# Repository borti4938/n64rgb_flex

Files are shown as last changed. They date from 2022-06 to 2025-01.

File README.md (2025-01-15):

N64RGBv3 / N64RGB_Flex (PCB & Fw)
---

This repository contains all you need files to build your own DIY N64RGBv3 / N64RGB_Flex board.
Firmware is supplied in this repository, too.

Please don't ask me for selling a modding.
I either sell some prototypes on some forums marketplaces (which is very unlikely) or I don't have any of the boards.
This is a complete DIY modding project.
Everybody is on his own here.

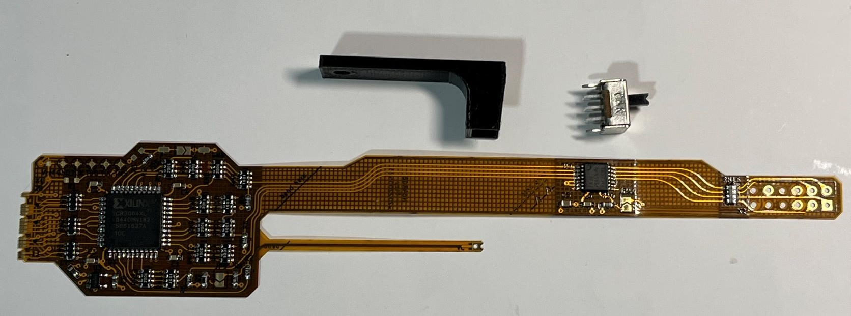
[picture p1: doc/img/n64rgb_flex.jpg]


**Note:** Images showing an older version of the PCB.
PCB was updated to reduce costs and due to CPLDs became end of life.

**WARNING:**
This is an advanced DIY project if you do everything on your own.
You need very good soldering skills.
The CPLD has 0.4mm fine pitched pins, the video amp 0.65mm pitch.
On the board there are some 4x0402 and 4x0603 resistor and ferrite bead arrays, as well as some tiny 0402 caps.
However, there might be some awesome shops out there selling the boards for a great price.

## Table of Contents

- [Checklist](https://github.com/borti4938/n64rgb_flex#checklist-how-to-build-the-project)
- [Assembly](https://github.com/borti4938/n64rgb_flex#assembly)
- [Installation](https://github.com/borti4938/n64rgb_flex#installation)
  - [1. Open the Console](https://github.com/borti4938/n64rgb_flex#1-open-the-console)
  - [2. Solder Work](https://github.com/borti4938/n64rgb_flex#2-solder-work)
  - [3. Jumper Setup](https://github.com/borti4938/n64rgb_flex#3-jumper-setup)
  - [4. Finish the Work](https://github.com/borti4938/n64rgb_flex#4-finish-the-work)
- [Firmware](https://github.com/borti4938/n64rgb_flex#firmware)
- [Cable Setup](https://github.com/borti4938/n64rgb_flex#cable-setup)

## Checklist: How to build the project

- Use PCB files (either [KiCad-PCB design file](./pcb/n64rgb_v3.kicad_pcb) or [Gerber files](./pcb/gerber/)) to order your own PCB with following specs (might be not comprehensive)  
  - Size: 160.28mm x 25.45mm
  - Layer: 2
  - FPC thickness: 0.12mm
  - Min hole size: dia 0.2mm / ring 0.4mm or lower
  - Min trace width / spacing: 0.15mm
  - Stiffener: Polyimide (bottom only)
  - Polyimide thickness: 0.15mm  
  There are two variants: _diy_ and _prod_. The _diy_ variant has larger via under the exposed pad and an opening in the stiffener under it in order to make soldering with standard soldering iron feasible. The _prod_ variant has smaller vias and no opening; so production assembly or use of soldering paste with hot air is mandatory.
- If you paln to use solder paste, do not forget to order a stencil for top
- Source the components you need, e.g. from Mouser or Digikey.  
  The BOM is available in [here](./doc/ibom.html).
- Wait for everything to arrive
- Assemble your PCB if you haven't use a PCBA service
- Flash the [Firmware](https://github.com/borti4938/n64rgb_flex#firmware) either before or after installation into the N64
- Set all jumpers

## Assembly

If you have all components available, you can start assembly your board.
**Please note**: if you plan to flash the firmware before assembly, go to the [Firmware](https://github.com/borti4938/n64rgb_flex#firmware) section first.
The documentation provides an [interactive BOM](./doc/ibom.html), which should guide you through the assbly.
There is no specific order for the assembly - just take your time.

Using non-clean flux (rosin based) is obviously recommended.
Even though it is "non-clean" I recommend cleaning everything afterwards (just for the visual finish).

Please double check everything for shorts once you finished your work.
Very important is that the power supply trace do not short to GND.
- 5V against GND (e.g. at C9 and at MultiOut pin 10 to 6)
- 3.3V against GND (e.g. at C11)
- 1.8V against GND (e.g. at C10)

Flash the firmware after assembly if you plan to do so.

## Installation

### 1. Open the console

- Remove Jumper Pak / Expansion Pak
- Remove screws from bottom side of the console  
(needs a 4.5mm gamebit tool)
- Lift top housing
- remove inner screws as marked  
(very last consoles made the heat sink design changed slightly)
- pull out the mainboard
- remove heat sink and RF shield
- **Hint** Now you have the chance to clean up your N64 shell

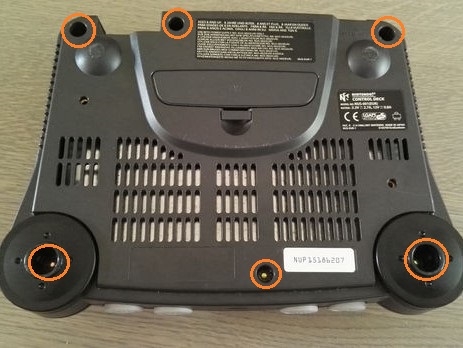
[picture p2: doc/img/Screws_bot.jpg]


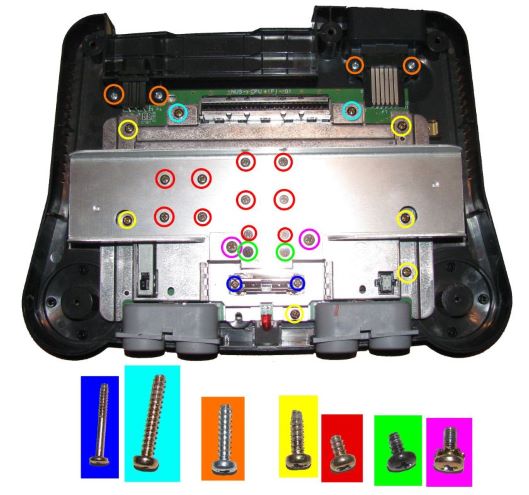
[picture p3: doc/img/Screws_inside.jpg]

(image by Zerberus (circuit-board.de user))

### 2. Solder Work

This PCB is designed as a custom flex cable which fits nicely into every N64.

#### 2.1 Digital inputs

Start with the digital side:
- Bend the input side like in an S-shape.  
This helps the solder connection to have minimal mechanical stress.

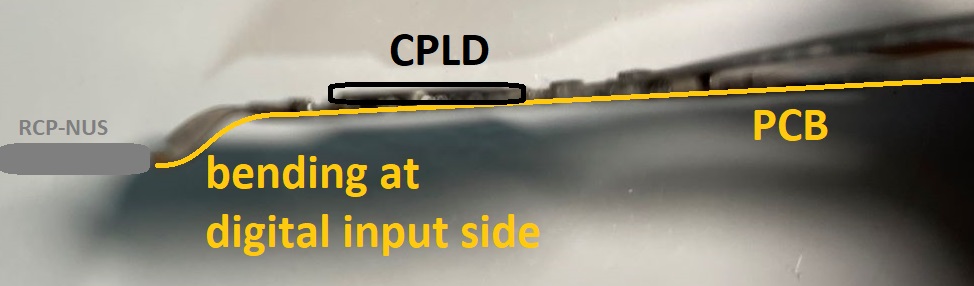
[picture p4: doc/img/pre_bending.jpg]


- Solder the RCP connector side to the RCP-NUS as shown
  - first pin bottom – 11
  - last pin to – 28
- Take your time for this step - after this one you are almost finished with your work

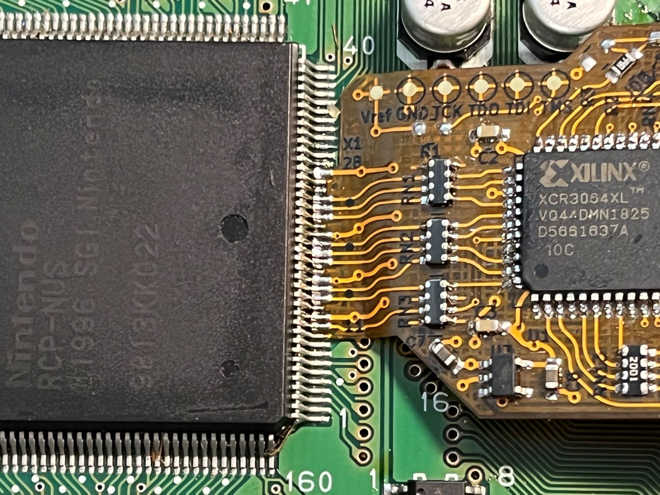
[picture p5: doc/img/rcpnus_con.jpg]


#### 2.2 Analog output

- Route the flex pcb to the MultiOut as shown.  
You need three bends:
  - Two rather sharp 90 degree ones
  - One round bending around the N64 PCB

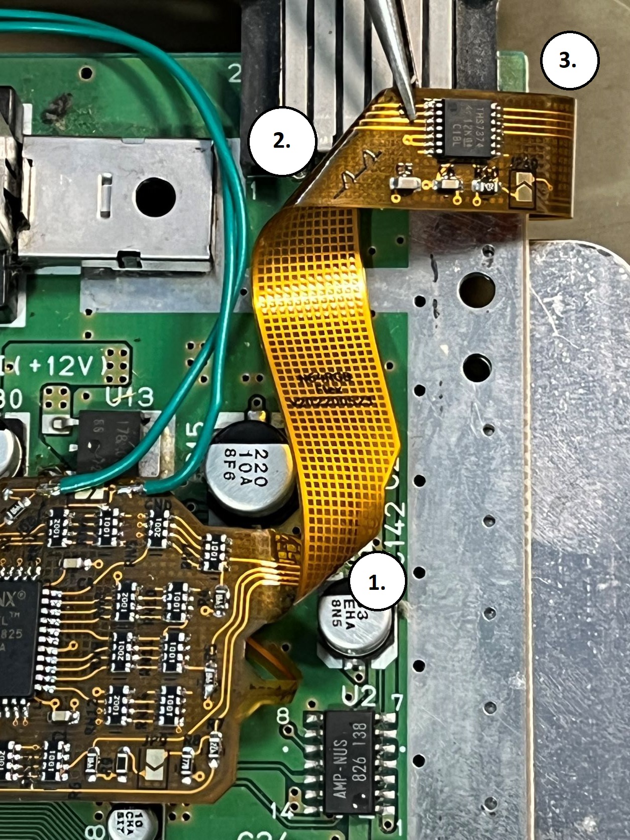
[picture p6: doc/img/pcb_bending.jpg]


- Solder the MultiOut footprint to the MultiOut pins

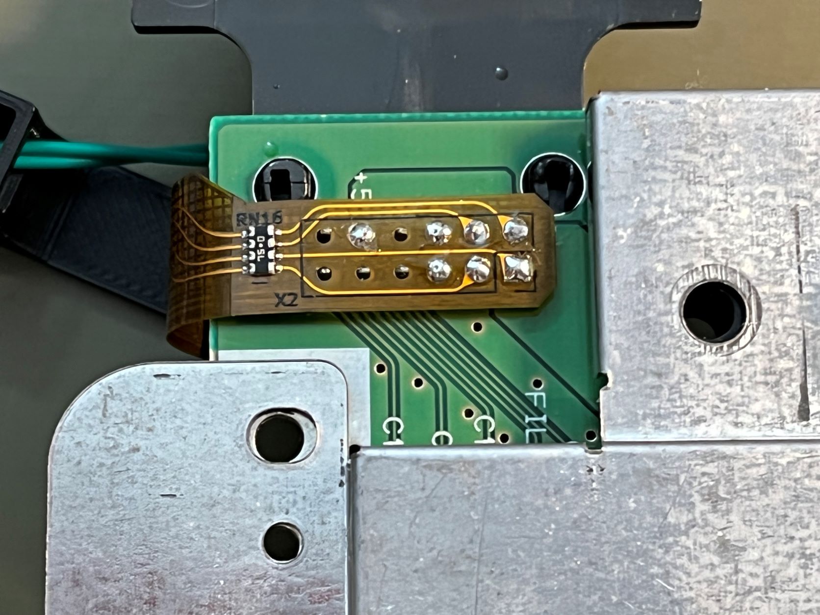
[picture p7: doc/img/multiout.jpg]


#### 2.3 Additional Step for NUS-CPU-01/-02/-03 boards

- remove R14
- or cut the trace going to pin 3 of the MultiOut

### 3. Jumper Setup

#### JP9 (CSYNC level @ pin 3 MultiOut)

- opened: appr. 1.87V @ 75ohm termination, i.e. needs a resistor inside the sync wire further attenuating the signal. Designed to work for cables with 470 ohm resistor inside resulting in appr. 450mV @ 75ohm termination
- closed: appr. 300mV @ 75ohm termination suitable for pass through wired cables at sync, works with standard TV / scaler setup

#### JP10 (low pass filter THS7374)

- opened: use low pass filter
- closed: bypass

#### JP11 - JP13 (Cable)

- all opened: NTSC cable
- all closed: PAL cable

#### JDB

For this jumper, it is recommended to use a slide switch (part no. is provided in the [BOM](./doc/ibom.html))

- opened: do not use vi-deblur for 240p output
- closed: permanently use vi-deblur for 240p output (not recommended at all)

### 4. Finish the Work

#### 4.1 VI-Deblur Switch

If you source the switch as provided in the [BOM](./doc/ibom.html), you can use [this 3D mount](https://www.thingiverse.com/thing:4584239) for a clean installation.
A copy of the STL is also provided [here](./3d_print/).
Please note and respect the license of the switch!

- Prepare the switch by cutting off two pins and a housing pin
- solder two wire of appr. 10cm length to a middle and an outside pin of the switch (same side)

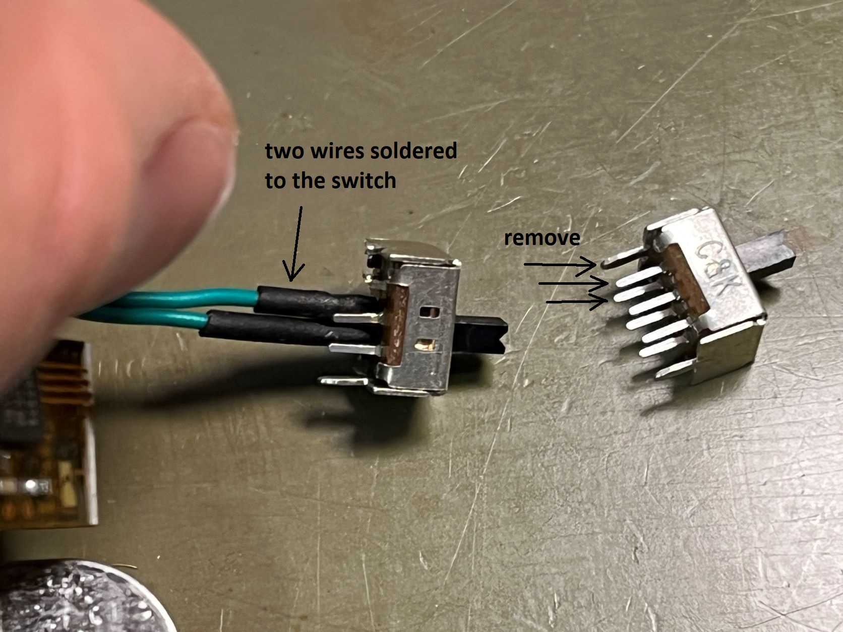
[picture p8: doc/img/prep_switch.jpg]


- run the wires through the 3d printed mount to the flex pcb
- solder the wires to the pads next to the JDB jumper

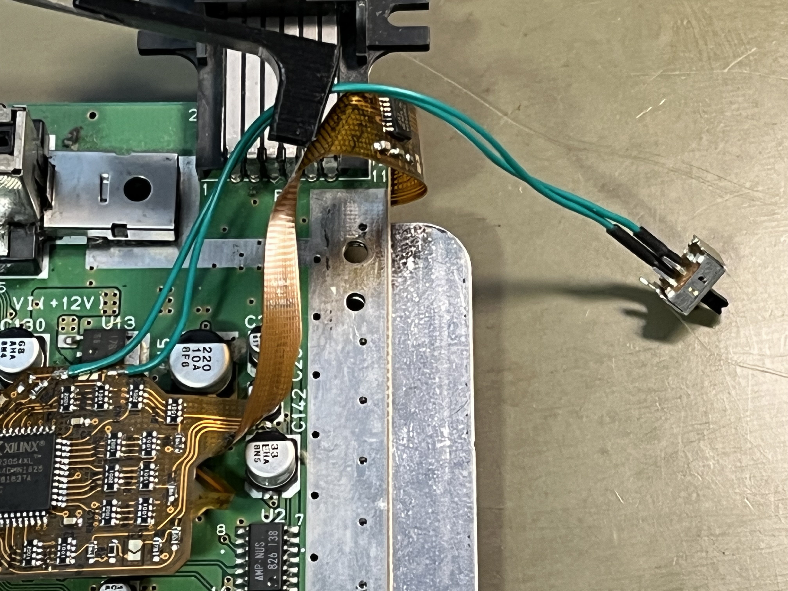
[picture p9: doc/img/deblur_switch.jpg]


#### 4.2 Putting everything back together

- Before putting everyything back together, isolate the top RF shield at the area where the flex PCB is routed.

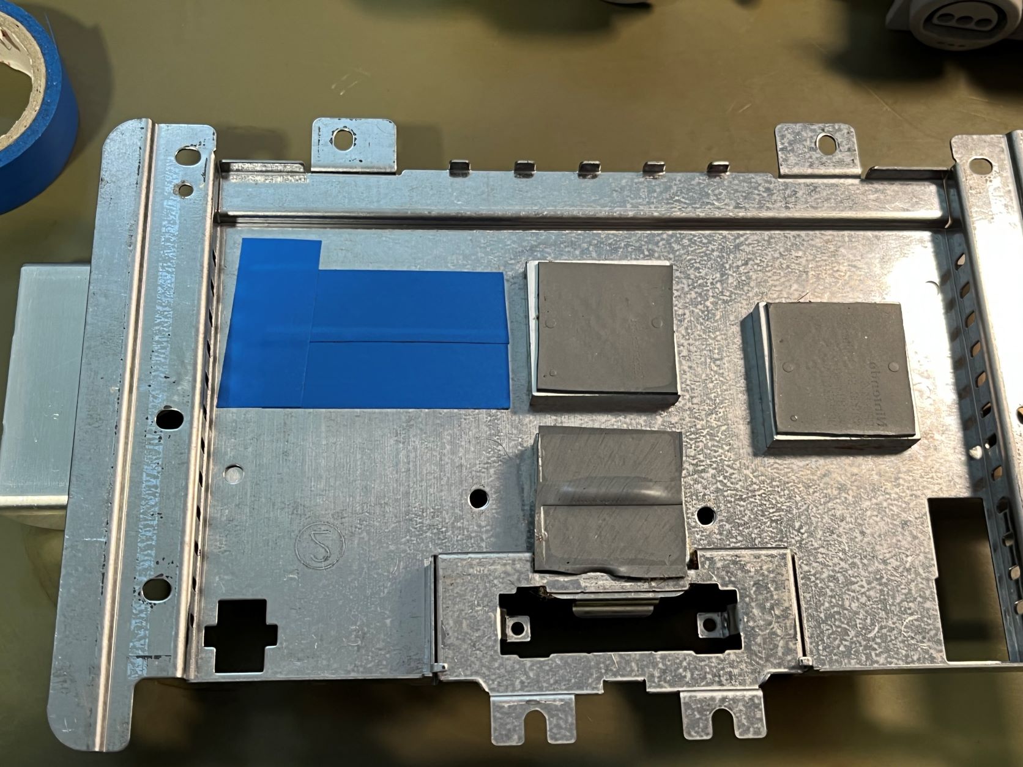
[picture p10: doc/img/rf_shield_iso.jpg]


- Flash the firmware if not already done (go to section [Firmware](https://github.com/borti4938/n64rgb_flex#firmware)).
- Assemble the top RF shield
- Make a short test if everything is working as expected
- Screw the N64 mainboard into the bottom shell with the deblur switch attached as shown

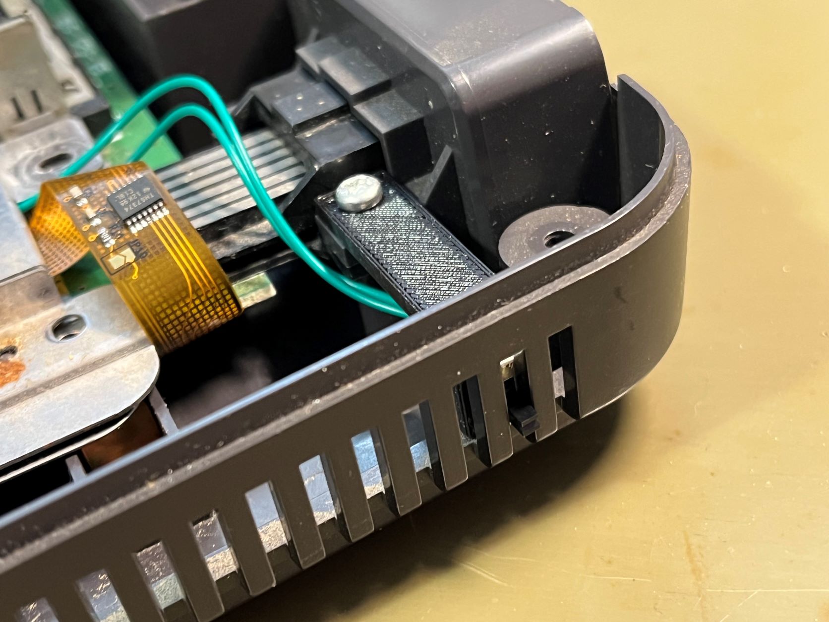
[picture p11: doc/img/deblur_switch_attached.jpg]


- Close the N64

## Firmware

Flashing the firmware to the CPLD is required to get the modding board working.
The firmware file depends on the CPLD you have.
Supported CPLDs are
- from Altera (IntelFPGA): 5M80ZE64C5N

For programming the firmware you need to have:
- [USB Blaster](https://www.digikey.de/de/products/detail/terasic-inc/P0302/2003484) or similar
- Quartus Programmer which is part of the [Quartus Prime Design Software](https://www.intel.com/content/www/us/en/software-kit/825278/intel-quartus-prime-lite-edition-design-software-version-23-1-1-for-windows.html) (link is from Version 23.1.1, but every other version may will work, too)
- Programming pads are south of the CPLD (bottom edge of the PCB) and are from left to right
  - TM**S**, TD**I**, T**C**K, TD**O**, **G**ND, and **V**ref
  - If you flash the firmware prior to installation, you also need to connect pads **G**ND and **5V** to supply the board with 5V for programming.
  - If you flash the firmare after installation, you can simply power the N64 during programming.

Here are two pictures of the noted pads.

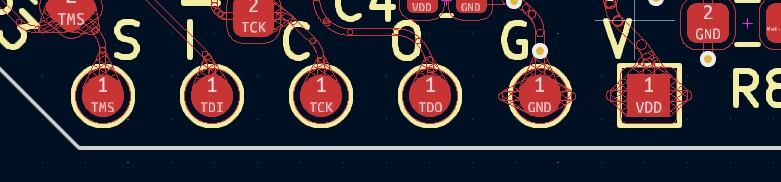
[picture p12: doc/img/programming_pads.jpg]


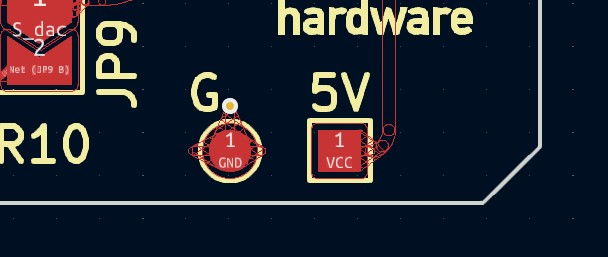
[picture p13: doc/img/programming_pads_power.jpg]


Flash the firmware using the following steps:
- Open the programming software
- Load the firmware binary
  - for the [5M80ZE64](./fw/output_files/n64rgb_flex.pof)
- Select the programmer cable if not already selected
- Select Program and Verify
- Run the programmer

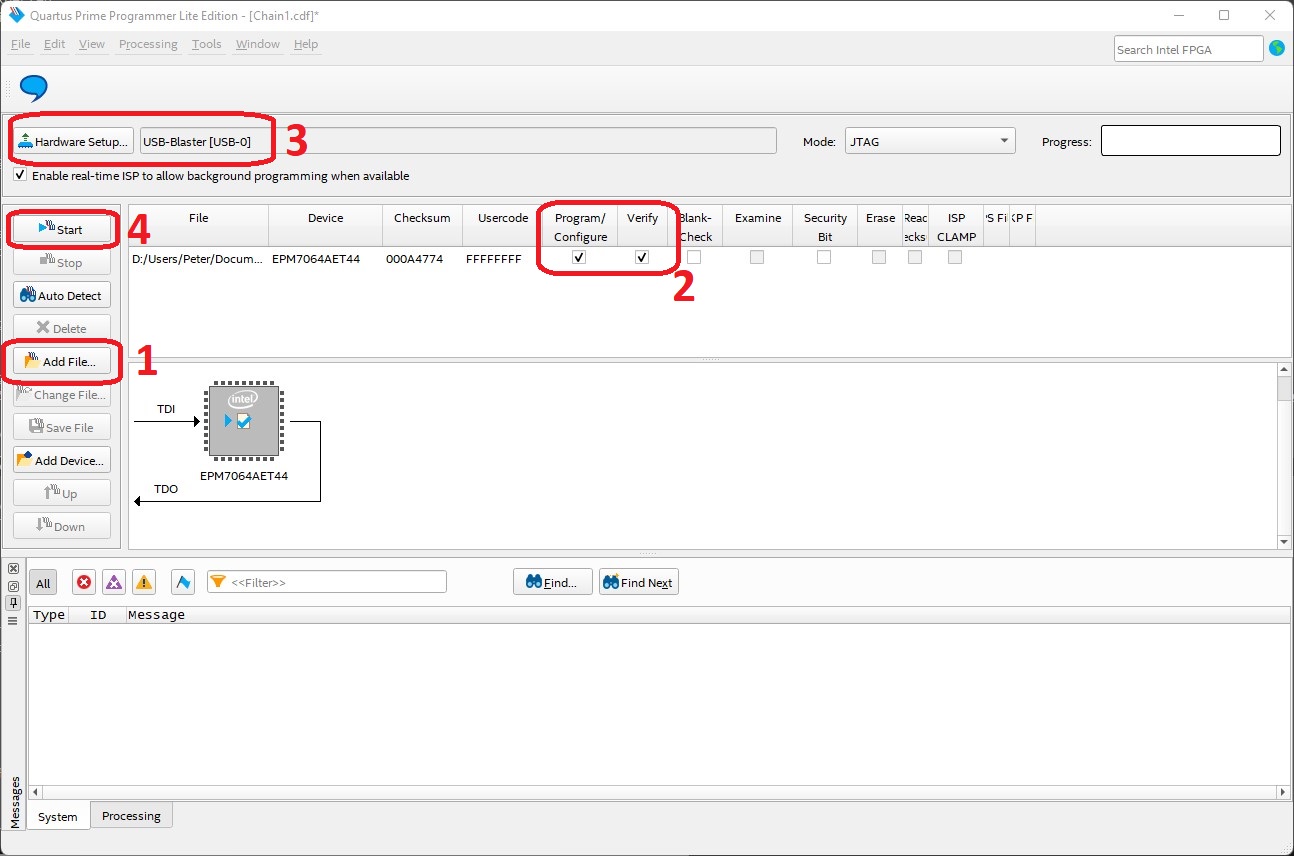
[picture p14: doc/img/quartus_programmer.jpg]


## Cable Setup

#### NTSC SNES Cable

Cable setup is as like as a (standard) RGB cable for the NTSC-SNES

| Signal | Pin MultiOut | Pin SCART | Ref. GND in SCART | Note |
|:---|:---|:---|:---|:-----|
| Red | 1 | 15 | 13 | Using a 220uF cap in series is possible |
| Green | 2 | 11 | 9 | Using a 220uF cap in series is possible |
| Blue | 4 | 7 | 5 | Using a 220uF cap in series is possible |
| Sync | 3, 7 or 9 | 20 | 17 | Pin: See installation, Cable: see notes below |
| GND | 5, 6 | 4,5,9,13,17,18,21 | Pin 21 @ SCART: outer shield |
| +5V | 10 | 16 | 18 | SCART: use a 180ohm resistor in series |
| Audio left | 11 | 6 | 4 | |
| Audio right | 12 | 2 | 4 | |

#### PAL SNES Cable

Cable setup is as like as a (standard) RGB cable for the PAL-SNES

| Signal | Pin MultiOut | Pin SCART | Ref. GND in SCART | Note |
|:---|:---|:---|:---|:-----|
| Red | 1 | 15 | 13 | 75ohm resistor to GND (pin 13) |
| Green | 2 | 11 | 9 | 75ohm resistor to GND (pin 9) |
| Blue | 4 | 7 | 5 | 75ohm resistor to GND (pin 5) |
| Sync | 3, 7 or 9 | 20 | 17 | Pin: See installation, Cable: see notes below |
| GND | 5, 6 | 4,5,9,13,17,18,21 | Pin 21 @ SCART: outer shield |
| +5V | 10 | 16 | 18 | SCART: use a 180ohm resistor in series |
| Audio left | 11 | 6 | 4 | |
| Audio right | 12 | 2 | 4 | |

#### Notes on Sync:

- If you have a series resistor in you cable make sure that JP9 is opened!
- If you have a straightly wired sync connection make sure that JP9 is closed!

#### RGB cables:

- If you buy an RGB cable,
  - NTSC: buy a typical RGB cable for a NTSC SNES with sync on luma (MultiAV pin 7) or sync on csync (MultiAV pin 3).
  - PAL: buy a typical RGB cable for a PAL SNES with sync on luma (MultiAV pin 7). You can modify the cable to use sync on csync (MultiAV pin 3).
- If you bought a raw csync cable and if you use the 75ohm output, please ensure to set JP9 correctly

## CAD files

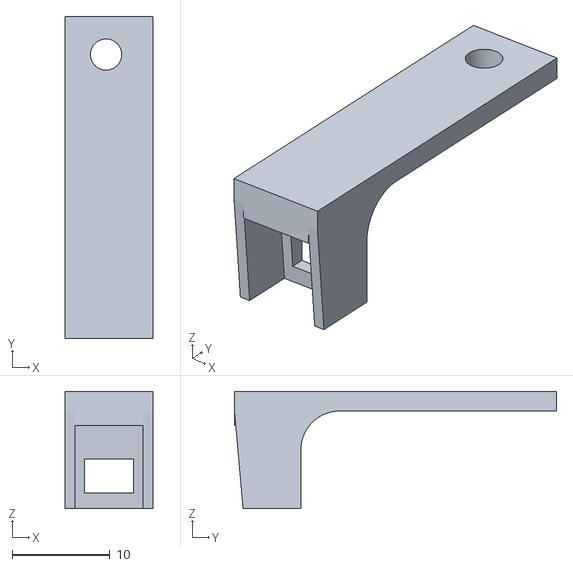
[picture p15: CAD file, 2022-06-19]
3d_print/N64RGB_Deblur_Switch_Mount.stl
9.00 x 33.0 x 12.0

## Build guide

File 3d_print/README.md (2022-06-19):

N64RGB Deblur Switch Mount by DragonsHoard
---

This mount is designed by DragonsHoard.
All credits for this design goes to him.
You can find the original source [here at thningiverse.com](https://www.thingiverse.com/thing:4584239).

This project is licensed under the [Creative Commons - Attribution](https://creativecommons.org/licenses/by/4.0/) license.
By downloading this thing, you agree to abide by the license: Creative Commons - Attribution - Non-Commercial - No Derivatives.

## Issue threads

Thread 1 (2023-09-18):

not working

Radeon91, 2023-09-18:
hello, I have built this but I can't get it to work.
once programmed and soldered in console, if i connect a super famicom scart cable i get video, but if i jumper any of the colors to ground the image does not change, so i assume that it is not working in rgb mode, but in composite video. i have tried to unsolder the composite video pin and force the sync that comes out of the mod, but in this case i get no image, i have also tried to use luma as sync, but without better result.
I have also reworked soldering, soldered several from 0, I have also checked the pump, resistors, etc.

What should I check more?

borti4938, 2024-09-07:
Sorry, haven't recognized this issue. All I can say is to double check every solder connection. No picture at all sounds linke an issue on clock or data sync line.

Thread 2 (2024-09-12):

Colors look weird

Kopite11, 2024-09-12:
Hello, I just installed this mod on my N64 (Board: NUS-CPU-05), but the on screen colors on look off...

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

Tried opening/closing JP9 but the issue persist.

I'm using an HDRetrovision SNES Component cable and a RetroTink 5X Pro.

Do I need a special jumper setting for my setup?

Checked my soldering for shorts and continuity and everything is properly soldered.

borti4938, 2024-10-10:
Looks like all colors are there, but probably some bits missing on each color. So my best guess is to double check connections from RCP-NUS data to CPLD.

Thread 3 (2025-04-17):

Issues with RetroTink 4K

duncan1111, 2025-04-17:
I have a pal n64 with n64rgb flex.

A pal sync on luma scart cables from retro gaming cables.

JP9 is closed and so are JP11-13

Luma and composite are disable on the n64 motherboard. Pin3 of the av port is jumped to pin7 & pin9.

Console works with tv, OSSC and rad2x but I get nothing on the retrotink 4KCE.

Updated to latest firmware on retrotink.

I get nothing - no audio or video

Any ideas?

Thank you 🙏🏻

duncan1111, 2025-04-18:
The person using it had an ever drive in ntsc mode 🤦

Closed 2025-04-18.

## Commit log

2022-07-22 add jumper to select between NTSC and PAL SNES style RGB cables
    [n64rgb_v3-B_Cu.gbr, n64rgb_v3-B_Mask.gbr, n64rgb_v3-B_Paste.gbr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]
2025-01-15 Update PCB for use with 5M80ZE64 CPLD
    [n64rgb_v3-B_Cu.gbr, n64rgb_v3-B_Mask.gbr, n64rgb_v3-B_Paste.gbr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]
